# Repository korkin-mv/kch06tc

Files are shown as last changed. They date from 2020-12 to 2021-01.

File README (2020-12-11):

KCH06TC

This is a personal project of the controller for the control of the terrarium.

The board was developed from components available to the author, and therefore 
the project should be presented as an introduction and not in any way a 
repetition.

License: MIT.
Copyright (c) 2020 Mihail Korkin <korkin_mv@protonmail.ch>.

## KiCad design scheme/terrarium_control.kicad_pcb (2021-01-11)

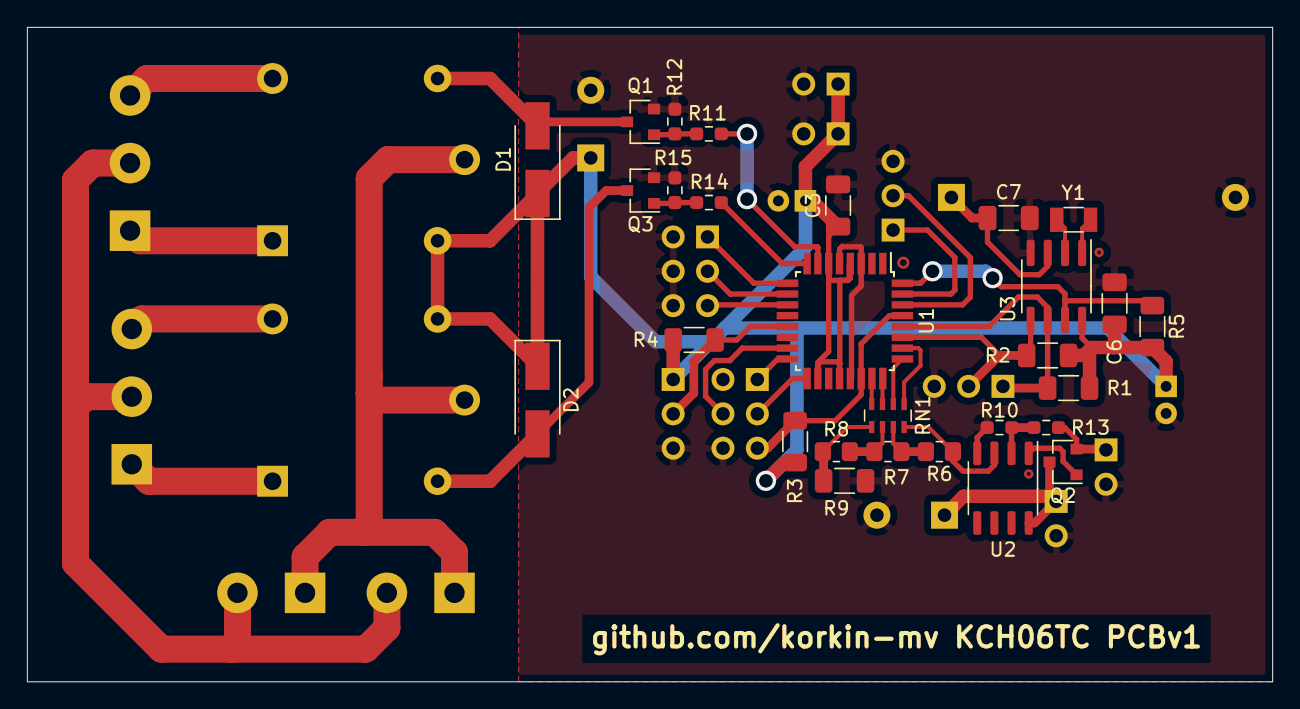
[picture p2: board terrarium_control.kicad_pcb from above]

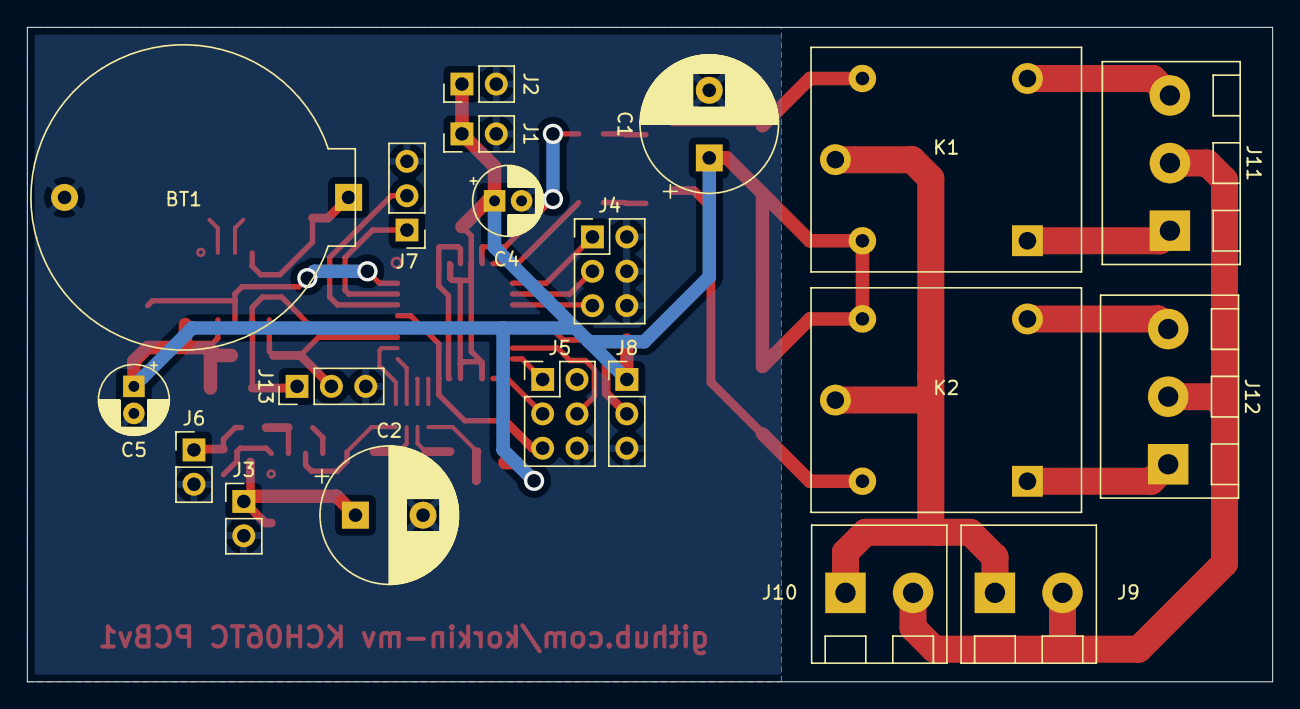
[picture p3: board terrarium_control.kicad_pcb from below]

Board: 2 copper layers, 92.1 x 48.4 mm, 48 parts (20 on the bottom side), 42 nets.

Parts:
BT1: CR2032; batt_holder
C1, C2: 1mF; CP_Radial_D10.0mm_P5.00mm
C3, C6: 100nF; C_1206_3216Metric_Pad1.33x1.80mm_HandSolder
C4, C5: 47uF; CP_Radial_D5.0mm_P2.00mm
C7: 10nF; C_1206_3216Metric_Pad1.33x1.80mm_HandSolder
D1, D2: M5; D_SMA_Handsoldering
J1: 5V_IN; PinHeader_1x02_P2.54mm_Vertical
J2: 5V_OUT; PinHeader_1x02_P2.54mm_Vertical
J3: 12V_IN; PinHeader_1x02_P2.54mm_Vertical
J4: SWITCHERS; PinHeader_2x03_P2.54mm_Vertical
J5: ICSP; PinHeader_2x03_P2.54mm_Vertical
J6: FUN; PinHeader_1x02_P2.54mm_Vertical
J7: UART; PinHeader_1x03_P2.54mm_Vertical
J8: ONE_WIRE; PinHeader_1x03_P2.54mm_Vertical
J9: 220V_IN; DG128-5.0-02P
J10: 220V_OUT; DG128-5.0-02P
J11: LAMP0; DG128-5.0-03P
J12: LAMP1; DG128-5.0-03P
J13: I2C; PinHeader_1x03_P2.54mm_Vertical
K1, K2: NRP-10-C-05D; NRP-10-C
Q1, Q3: 2N7002; SOT-23
Q2: BC817; SOT-23
R1, R2, R3, R4, R5, R9: 4.7k; R_1206_3216Metric_Pad1.30x1.75mm_HandSolder
R6, R7, R8: 2.2k; R_0805_2012Metric_Pad1.20x1.40mm_HandSolder
R10: 33k; R_0603_1608Metric_Pad0.98x0.95mm_HandSolder
R11, R14: 910; R_0603_1608Metric_Pad0.98x0.95mm_HandSolder
R12, R15: 9.1k; R_0603_1608Metric_Pad0.98x0.95mm_HandSolder
R13: 51k; R_0603_1608Metric_Pad0.98x0.95mm_HandSolder
RN1: 4.7k; R_Array_Concave_4x0603
U1: ATmega88PA-AU; TQFP-32_7x7mm_P0.8mm
U2: LM358; SO-8_3.9x4.9mm_P1.27mm
U3: DS1307Z+; SOIC-8_3.9x4.9mm_P1.27mm
Y1: 32768Hz; FC-135

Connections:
220V_N: J9.2, J10.2, J11.2, J12.2
220V_PHASE: J9.1, J10.1, K1.4, K2.4
+5V: C1.1, C3.1, C4.1, C5.1, C6.1, D1.1, D2.1, J1.1, J2.1, J8.1, K1.5, K2.3, R1.2, R2.2, R3.2, R4.2, R5.2, U1.4, U1.6, U1.18, U1.20, U3.8
+12V: C2.1, J3.1, Q2.3, U2.8
+BATT: BT1.1, C7.2, U3.3
/X+: U3.1, Y1.1
/X-: U3.2, Y1.2
DAC: R6.1, RN1.8, U2.3
DAC0: RN1.4, U1.23
DAC1: RN1.3, U1.24
DAC2: RN1.2, U1.25
DAC3: RN1.1, U1.26
ENABLE: J4.1, U1.9
FORCE0: J4.3, U1.10
FORCE1: J4.5, U1.11
FUN: J6.1, Q2.2, R13.2
GND: BT1.2, C1.2, C2.2, C3.2, C4.2, C5.2, C6.2, C7.1, J1.2, J2.2, J3.2, J4.2, J4.4, J4.6, J5.6, J6.2, J7.3, J8.3, J13.3, Q1.2, Q3.2, R9.2, R10.2, R12.1, R15.1, U1.3, U1.5, U1.21, U2.4, U3.4
MCU_RXD: J7.2, U1.30
MCU_TXD: J7.1, U1.31
MISO: J5.1, U1.16
MOSI: J5.4, U1.15
unnamed: D1.2, K1.3, Q1.3
unnamed: D2.2, K2.5, Q3.3
unnamed: J11.1, K1.1
unnamed: J11.3, K1.2
unnamed: J12.1, K2.1
unnamed: J12.3, K2.2
unnamed: Q1.1, R11.2, R12.2
unnamed: Q2.1, U2.1
unnamed: Q3.1, R14.2, R15.2
unnamed: R6.2, R7.1, RN1.7
unnamed: R7.2, R8.1, RN1.6
unnamed: R8.2, R9.1, RN1.5
unnamed: R10.1, R13.1, U2.2
ONE_WIRE: J8.2, R4.1, U1.13
RELAY0: R11.1, U1.7
RELAY1: R14.1, U1.8
RESET: J5.5, R3.1, U1.22, U1.29
SCK: J5.3, U1.17
SCL: J13.1, R1.1, U1.28, U3.6
SDA: J13.2, R2.1, U1.27, U3.5
SQW: R5.1, U1.32, U3.7

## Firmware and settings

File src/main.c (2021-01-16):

#include <avr/interrupt.h>

#include "defines.h"
#include "scheduler.h"
#include "gpio.h"
#include "vt.h"

#include "sh/relay.h"
#include "sh/help.h"
#include "sh/echo.h"

static sh_relay_data_t _sh_relay_data;
static sh_help_data_t _sh_help_data;
static sh_echo_data_t _sh_echo_data;

static shell_program_t _shell_programs[] =
{
    {
        .func = &sh_help,
        .name = &sh_help_name,
        .description = &sh_help_description,
        .data = &_sh_help_data
    },
    {
        .func = &sh_echo,
        .name = &sh_echo_name,
        .description = &sh_echo_description,
        .data = &_sh_echo_data
    },
    {
        .func = &sh_relay,
        .name = &sh_relay_name,
        .description = &sh_relay_description,
        .data = &_sh_relay_data
    }
};

static shell_data_t _shell_data;
static vt_data_t _vt_data;

static ALWAYS_INLINE void init(void)
{
    gpio_init();
    shell_init(&_shell_data, _shell_programs, sizeof(_shell_programs)/sizeof(_shell_programs[0]));
    vt_init(&_vt_data, &_shell_data);
}

static task_t _tasks[] =
{
    { .func = &vt_task, .data = &_vt_data, .enable = true }
};

OS_MAIN int main(void)
{
    init();
    sei();
    schedule(_tasks, sizeof(_tasks)/sizeof(_tasks[0]));
}

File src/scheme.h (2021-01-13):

#ifndef SCHEME_H
#define SCHEME_H

#include <avr/io.h>

#define ONE_WIRE_PORT PORTB
#define ONE_WIRE_PIN  PINB
#define ONE_WIRE_DDR  DDRB
#define SCH_ONE_WIRE  PB1

#define UART_PORT PORTB
#define UART_DDR  DDRB
#define UART_PIN  PINB
#define SCH_MOSI  PB3
#define SCH_MISO  PB4
#define SCH_SCK   PB5

#define RELAYS_PORT PORTB
#define RELAYS_PIN  PINB
#define RELAYS_DDR  DDRB
#define SCH_RELAY0  PB6
#define SCH_RELAY1  PB7

#define DAC_PORT PORTC
#define DAC_PIN  PINC
#define DAC_DDR  DDRC
#define SCH_DAC0 PC0
#define SCH_DAC1 PC1
#define SCH_DAC2 PC2
#define SCH_DAC3 PC3

#define I2C_PORT PORTC
#define I2C_PIN  PINC
#define I2C_DDR  DDRC
#define SCH_SDA  PC4
#define SCH_SCL  PC5

#define USART_PORT  PORTD
#define USART_PIN   PIND
#define USART_DDR   DDRD
#define SCH_MCU_RXD PD0
#define SCH_MCU_TXD PD1

#define SQW_PORT PORTD
#define SQW_PIN  PIND
#define SQW_DDR  DDRD
#define SCH_SQW  PD2

#define SWITCHS_PORT PORTD
#define SWITCHS_PIN  PIND
#define SWITCHS_DDR  DDRD
#define SCH_ENABLE   PD5
#define SCH_FORCE0   PD6
#define SCH_FORCE1   PD7

#endif//SCHEME_H

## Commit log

2020-11-28 Add scheme and datasheets
    [terrarium_control.kicad_pcb, terrarium_control.sch]
2020-11-28 Fixed missing components
    [terrarium_control.sch]
2020-11-29 Assign PCB footprints to schematic symbols and add I2C connector
    [terrarium_control.sch]
2020-11-29 Added elements to the board and assigned track classes
    [terrarium_control.kicad_pcb]
2020-11-29 Add custom battery holder
    [terrarium_control.sch]
2020-11-29 ~50% of board layout completed
    [terrarium_control.kicad_pcb, terrarium_control.sch]
2020-11-30 Fix pin assigns for input switchers
    [terrarium_control.sch]
2020-11-30 Board layout completed
    [terrarium_control.kicad_pcb, terrarium_control.sch]
2020-11-30 Add project name and github qrcode on pcb
    [terrarium_control.kicad_pcb]
2020-11-30 Remove mask from 220V traces
    [terrarium_control.kicad_pcb]
2020-12-05 Work on bugs: Remove QR-code; Change track distance to 0.24 mm; Add plain ground tracks instead of filler zone.
    [terrarium_control.kicad_pcb]
2020-12-11 Board changed from single-sided to double-sided.
    [terrarium_control.kicad_pcb, terrarium_control.sch]
2020-12-11 Rename "kicad" to "scheme"; Add license and readme.
    [terrarium_control.kicad_pcb, terrarium_control.sch]
2021-01-11 [PCB] Fix DG128 size
    [terrarium_control.kicad_pcb]
2021-01-14 [Firmware] Add queue, uart, vt and scheduler functional.
